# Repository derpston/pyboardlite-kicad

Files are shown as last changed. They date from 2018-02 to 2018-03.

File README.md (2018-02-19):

KiCad design for a minimal PyBoard
--
Like a PyBoard, but sacks off everything unnecessary, like:

* SD card
* Accelerometer
* Second crystal for the RTC
* User button
* Lots of pin headers
* Most of the LEDs

Wait, so what /is/ included?
--

The bare essentials:

* Microcontroller (STM32F405RGT6)
* USB connector
* 3.3v voltage regulator
* Many caps for power supply conditioning
* Reset button
* 8MHz crystal
* An LED for status

Dependencies
--

Some of the parts used are available from [this KiCad part library](https://github.com/derpston/derplib-kicad) and you'll probably need that to make sense of the schematic or make any changes to it.

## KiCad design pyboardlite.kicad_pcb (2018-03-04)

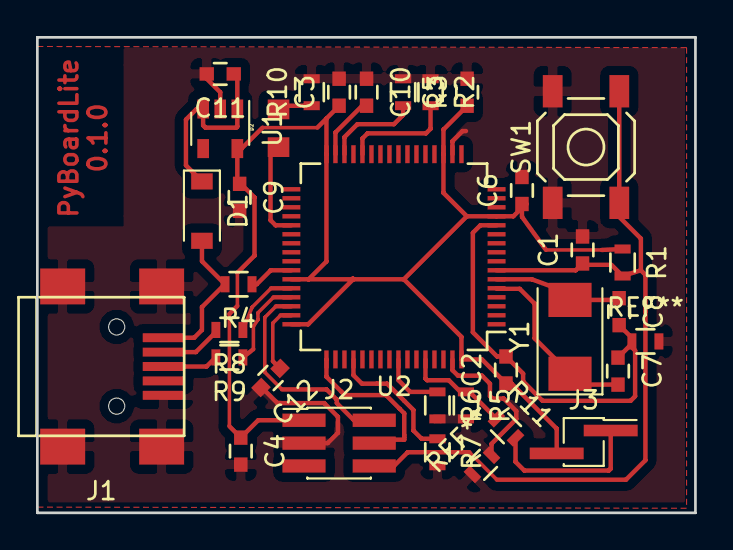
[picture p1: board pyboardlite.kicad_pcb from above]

Board: 2 copper layers, 36.6 x 26.4 mm, 32 parts (0 on the bottom side), 24 nets.

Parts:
C1, C3, C4, C5, C6: 100nF; C_0603
C2: 4.7uF; C_0603
C7, C8: 18pF; C_0603
C9, C10, C12: 2.2uF; C_0603
C11: 1uF; C_0603
D1: D_Schottky; D_SOD-123
D2: LED_Small; 150080GS75000
J1: USB_OTG; USB_Mini-B
J2: Conn_02x03_Odd_Even; Pin_Header_Straight_2x03_Pitch1.27mm_SMD
J3: DFU_Jumper; Pin_Header_Straight_1x02_Pitch1.27mm_SMD_Pin1Right
R1, R2, R3, R6, R7, R11: 10K; R_0603
R4, R10: 1K; R_0603
R5: 100K; R_0603
R8, R9: 22; R_0603
SW1: Button-PTM; SW_SPST_SKQG
U1: LP2980AIM5-3.3; SOT-23-5
U2: STM32F405RGT6; LQFP-64_10x10mm_Pitch0.5mm
Y1: 8MHz; Crystal_SMD_Abracon_ABM3-2pin_5.0x3.2mm

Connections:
+3V3: C2.1, C3.1, C4.1, C5.1, C6.1, C9.1, J2.1, J3.2, R1.1, U1.5, U2.13, U2.19, U2.32, U2.43, U2.48, U2.64
+5V: C11.1, D1.1, U1.1, U1.3
/NRST: C1.1, J2.6, R1.2, SW1.2, U2.7
/SWCLK: J2.4, U2.49
/SWDIO: J2.2, U2.46
GND: C1.2, C2.2, C3.2, C4.2, C5.2, C6.2, C7.1, C8.2, C9.2, C10.1, C11.2, C12.2, J1.5, J1.6, J2.3, R2.1, R3.1, R5.2, R6.2, R7.2, R10.2, SW1.1, U1.2, U2.12, U2.18, U2.63
unnamed: C7.2, U2.5, Y1.1
unnamed: C8.1, U2.6, Y1.2
unnamed: C10.2, U2.31
unnamed: C12.1, U2.47
unnamed: D1.2, J1.1, R4.2
unnamed: D2.1, R10.1
unnamed: D2.2, U2.37
unnamed: J1.2, R8.2
unnamed: J1.3, R9.2
unnamed: J3.1, R11.2
unnamed: R2.2, U2.28
unnamed: R3.2, U2.30
unnamed: R4.1, U2.42
unnamed: R6.1, U2.57
unnamed: R7.1, U2.52
unnamed: R8.1, U2.44
unnamed: R9.1, U2.45
unnamed: R5.1, R11.1, U2.60

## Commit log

2018-02-19 Initial commit.
    [pyboardlite.kicad_pcb, pyboardlite.sch]
2018-02-19 USB connector, SWD header, etc
    [pyboardlite.sch]
2018-02-20 Swapped SWD header for a 2x3 1.27mm socket, assigned all footprints.
    [pyboardlite.kicad_pcb, pyboardlite.sch]
2018-02-21 Swapping SWD header pin order
    [pyboardlite.kicad_pcb, pyboardlite.sch]
2018-02-22 Added LED, did initial board placement and track routing.
    [pyboardlite.kicad_pcb, pyboardlite.sch]
2018-02-28 Jiggery pokery
    [pyboardlite.kicad_pcb]
2018-03-04 Adding DFU jumper, moving a jumper resistor, enlarging the board slightly.
    [pyboardlite.kicad_pcb, pyboardlite.sch]
